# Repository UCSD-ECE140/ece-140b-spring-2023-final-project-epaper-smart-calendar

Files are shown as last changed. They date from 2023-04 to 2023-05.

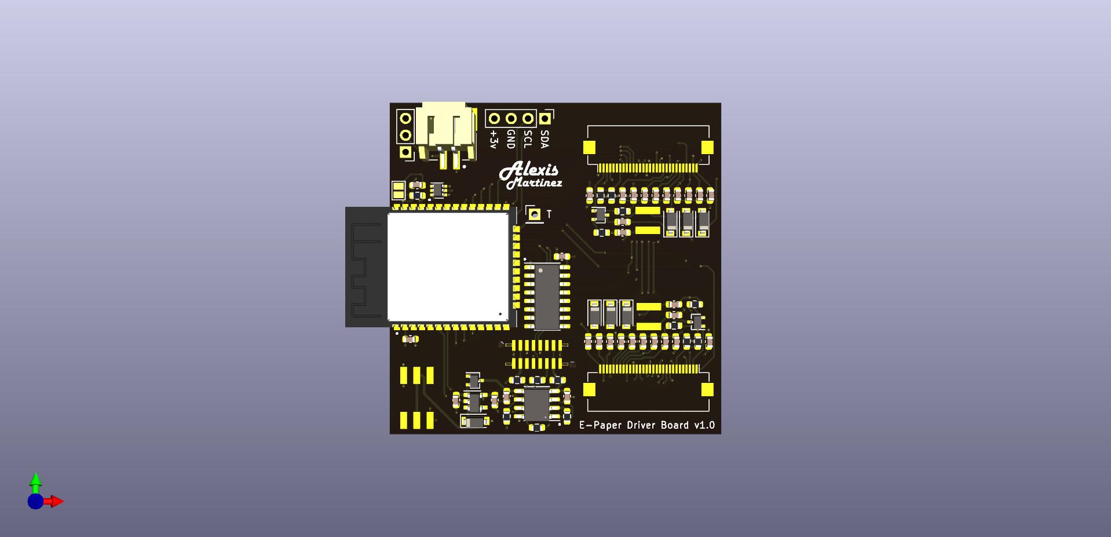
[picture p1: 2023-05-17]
PCB/Showcase Files/e_paper_display_driver_3d.jpg

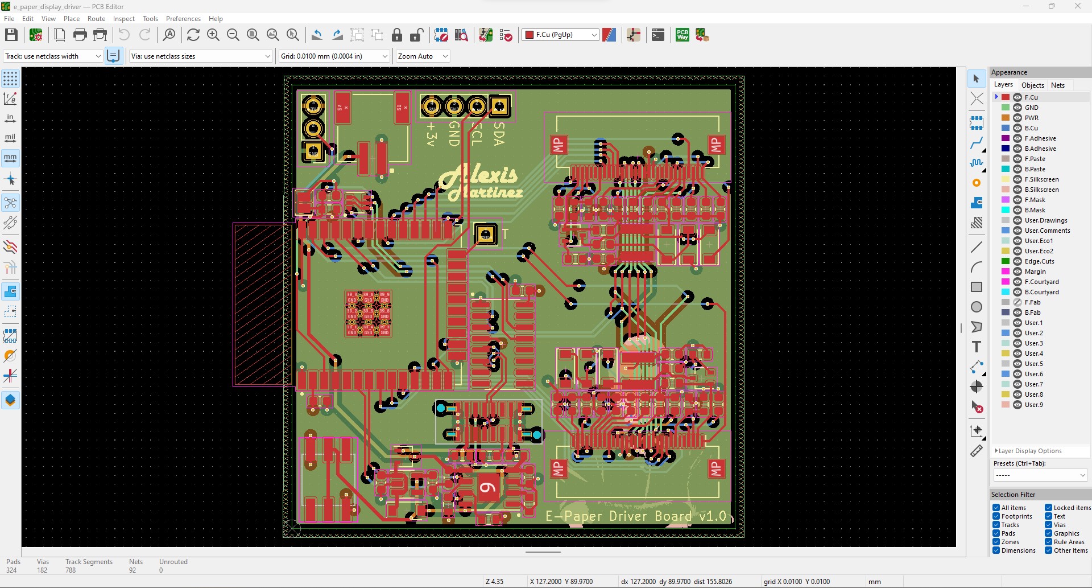
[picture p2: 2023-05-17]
PCB/Showcase Files/v1_screenshot_2d.jpg

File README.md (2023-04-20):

DEVELOPMENT SETUP:
Development is conducted using VS Code; the following extensions are required:
1. CPP Support (OPTIONAL: Syntax highlighting, misc. QoL CPP Extensions)
2. Arduino

Press control+shift+P and open the arduino library manager, then search for and install the following libraries:
1. WiFi
2. HTTPClient
3. ArduinoJson

TODO: ADD INSTRUCTIONS FOR BOARD UPLOAD

MISC. UNSORTED RESOURCES:
https://github.com/me-no-dev/arduino-esp32fs-plugin

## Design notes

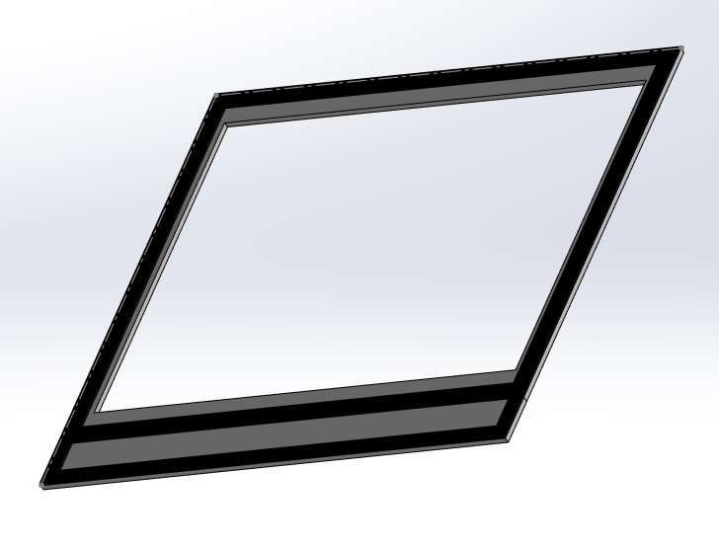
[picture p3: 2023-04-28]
E-Paper Calender CAD Files/Front Plate with Display Frame and Spacer.jpg

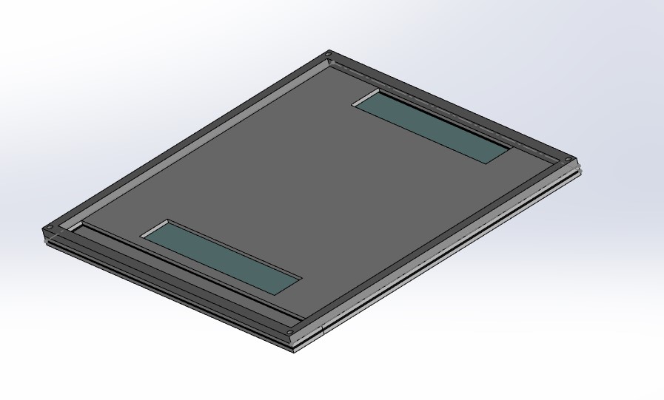
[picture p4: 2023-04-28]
E-Paper Calender CAD Files/Frame Attached to Backplate.jpg

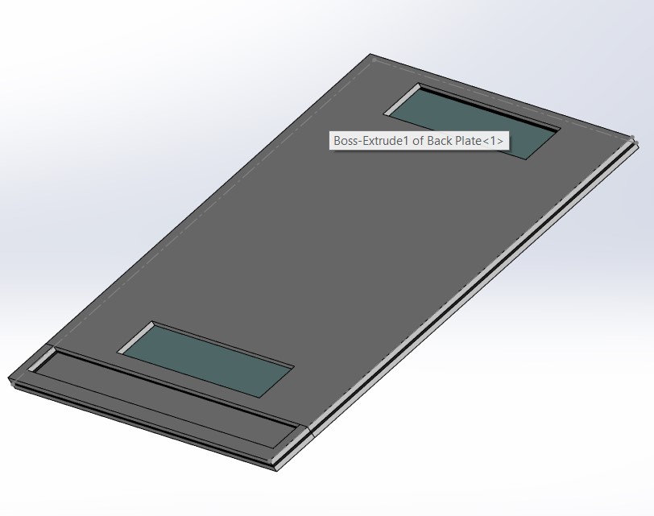
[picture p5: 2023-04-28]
E-Paper Calender CAD Files/Backplate Attached to Display Frame.jpg

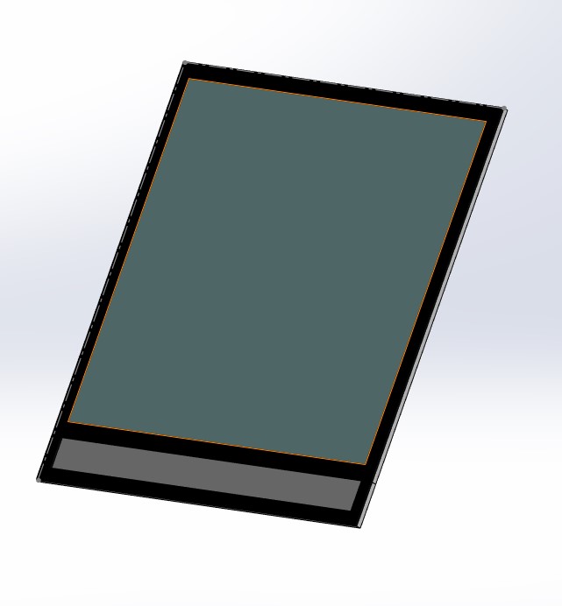
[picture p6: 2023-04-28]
E-Paper Calender CAD Files/Front Plate with Display Frame, Display, and Spacer.jpg

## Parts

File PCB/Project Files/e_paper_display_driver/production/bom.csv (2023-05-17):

Designator | Footprint | Quantity | Value | LCSC Part #
C1, C10, C11, C12, C14, C15, C16, C17, C18, C19, C2, C20, C21, C22, C23, C5, C6, C7, C8, C9 | 0603 | 20 | 1uF
C13, C3, C4 | 0603 | 3 | 100nF
C24, C25, C30, C31 | 0603 | 4 | 10uF
C26, C27, C28, C29 | 0603 | 4 | 4.7uF
D1 | D_SOD-123 | 1 | D_Shotkey
D2, D3, D4, D5, D6, D7 | D_SOD-123 | 6 | D
J1, J2 | Hirose_FH12-30S-0.5SH_1x30-1MP_P0.50mm_Horizontal | 2 | Conn_01x30
J3 | PinHeader_1x01_P2.54mm_Vertical | 1 | Conn_01x01
J4 | PinHeader_1x04_P2.54mm_Vertical | 1 | Conn_01x04
J5 | PinHeader_1x03_P2.54mm_Vertical | 1 | Conn_01x03
J6 | JST_S2B-PH-SM4-TB(LF)(SN) | 1 | S2B-PH-SM4
JP1 | SolderJumper-2_P1.3mm_Open_Pad1.0x1.5mm | 1 | SolderJumper_2_Open
L1, L2 | L_WPN4020H100MT | 2 | 10uH
Q1 | SOT-363_SC-70-6 | 1 | UMH3N
Q2, Q3 | SOT-323_SC-70 | 2 | Sil308EDL
Q4 | SOT-323_SC-70 | 1 | WST2005
R1, R10, R11, R15, R4, R5, R6, R8 | 0603 | 8 | 10k
R12, R13 | 0603 | 2 | 5.1k
R14 | 0603 | 1 | 1.2k
R2, R3 | 0603 | 2 | 3R
R7, R9 | 0603 | 2 | 1R
SW1 | TK-6580S-1 | 1 | SW_DPDT_x2
U1 | MODULE_ESP32-WROOM-32D | 1 | ESP32-WROOM-32D
U2 | SOIC-16_3.9x9.9mm_P1.27mm | 1 | CH340C
U3 | SOT-23-5 | 1 | ME6217C33M5G
U4 | HTSOP-8-1EP_3.9x4.9mm_P1.27mm_EP2.4x3.2mm | 1 | TP4056
USB1 | MC-110LS-L100 | 1 | USB_C_MC-110LS-L100

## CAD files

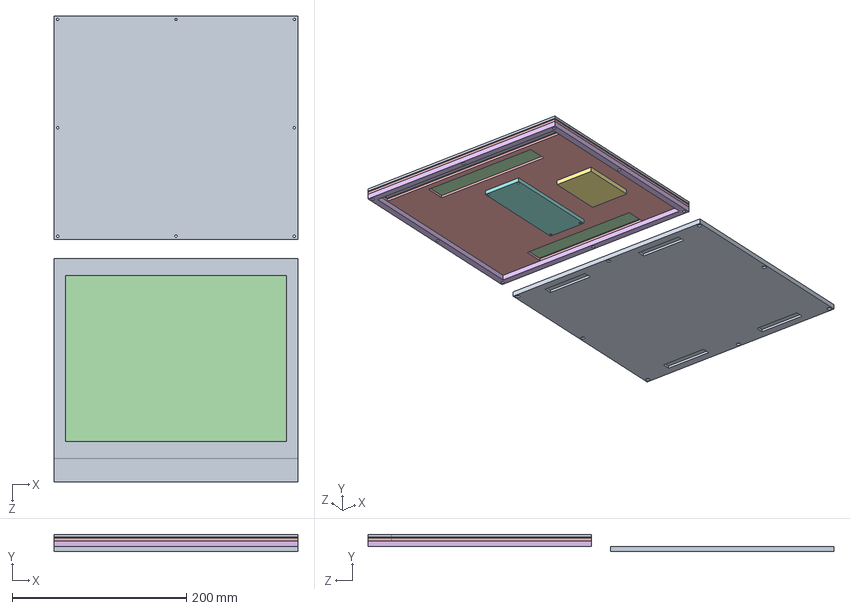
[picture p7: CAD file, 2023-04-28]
E-Paper Calender CAD Files/Assem1.SLDASM
280.0 x 19.6 x 535.4 mm
Front Plate
Display Frame Stand-In
Display Frame Spacer
Display Stand-in
Back Plate
Frame
Battery Stand-In
PCB Stand-in
Back Lid

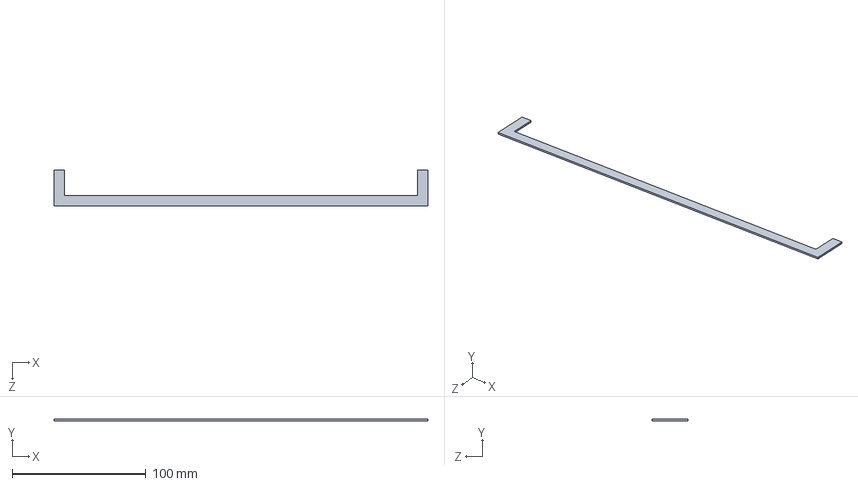
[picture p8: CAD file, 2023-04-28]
E-Paper Calender CAD Files/Display Frame Spacer.SLDPRT
280.0 x 1.25 x 27.0 mm

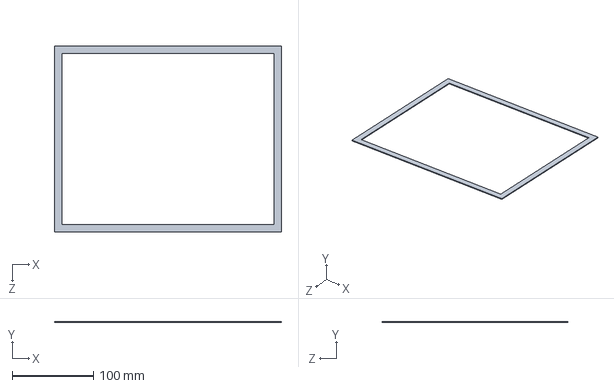
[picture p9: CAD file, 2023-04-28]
E-Paper Calender CAD Files/Display Frame Stand-In.SLDPRT
280.0 x 1.25 x 230.0 mm

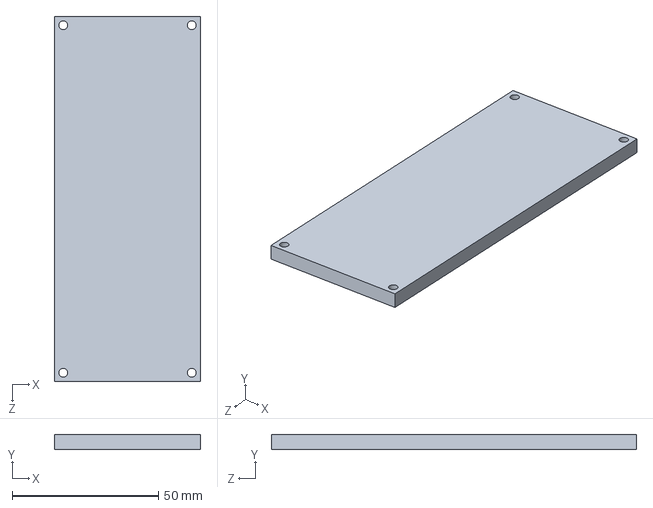
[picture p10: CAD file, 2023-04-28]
E-Paper Calender CAD Files/PCB Stand-in.SLDPRT
50.0 x 5.00 x 125.0 mm

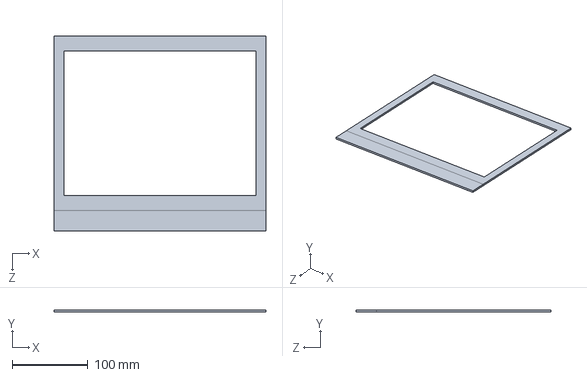
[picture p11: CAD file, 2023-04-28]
E-Paper Calender CAD Files/Front Plate.SLDPRT
280.0 x 3.00 x 257.0 mm

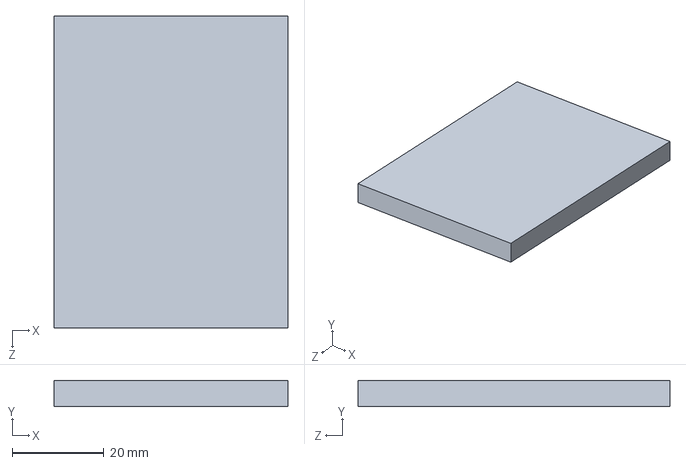
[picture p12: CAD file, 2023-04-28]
E-Paper Calender CAD Files/Battery Stand-In.SLDPRT
51.0 x 5.70 x 68.0 mm

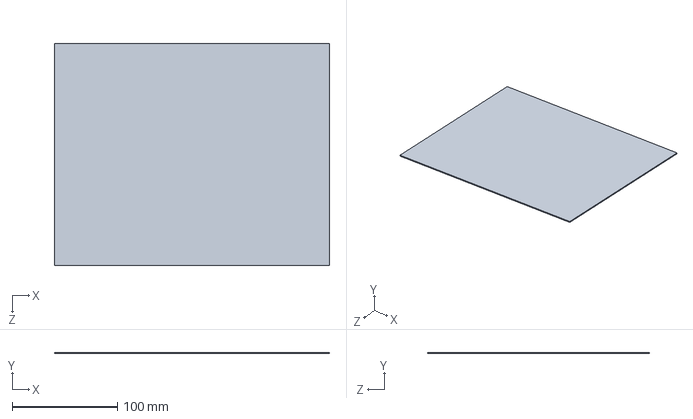
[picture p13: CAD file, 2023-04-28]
E-Paper Calender CAD Files/Display Stand-in.SLDPRT
261.0 x 1.25 x 211.0 mm

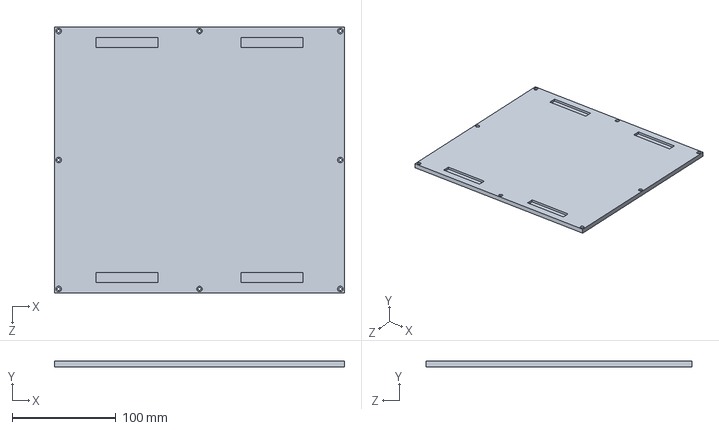
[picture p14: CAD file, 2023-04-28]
E-Paper Calender CAD Files/Back Lid.SLDPRT
280.0 x 6.00 x 257.0 mm

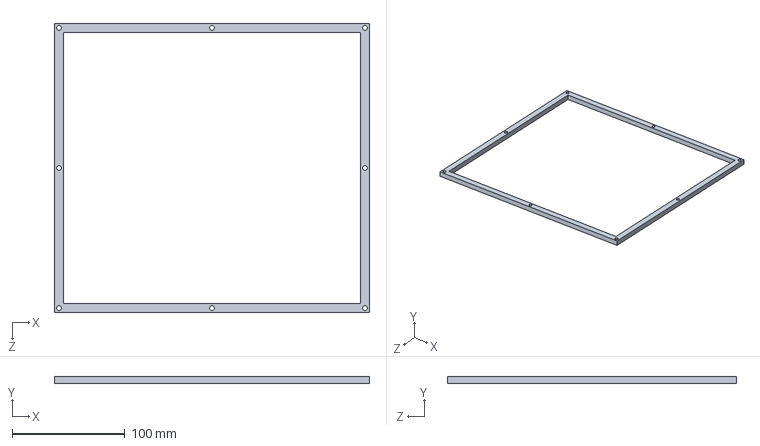
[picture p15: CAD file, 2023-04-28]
E-Paper Calender CAD Files/Frame.SLDPRT
280.0 x 6.35 x 257.0 mm

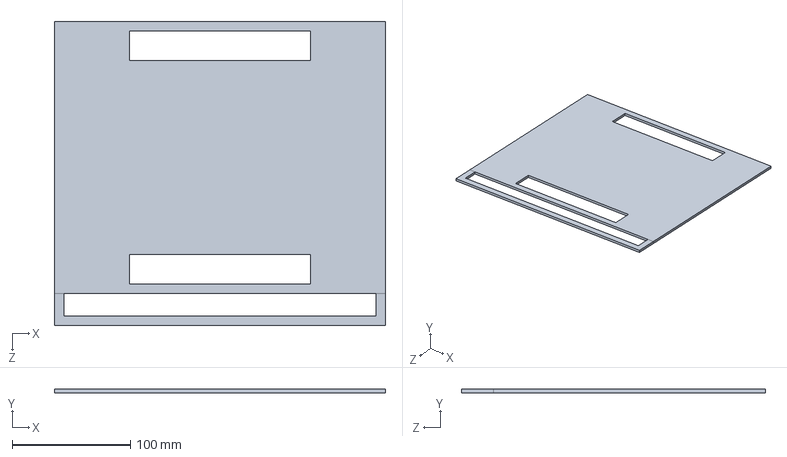
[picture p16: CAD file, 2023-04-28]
E-Paper Calender CAD Files/Back Plate.SLDPRT
280.0 x 3.00 x 257.0 mm

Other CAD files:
E-Paper Calender CAD Files/Back Plate.STL
E-Paper Calender CAD Files/Display Frame Stand-In.STL
E-Paper Calender CAD Files/Frame.STL
E-Paper Calender CAD Files/Front Plate.STL

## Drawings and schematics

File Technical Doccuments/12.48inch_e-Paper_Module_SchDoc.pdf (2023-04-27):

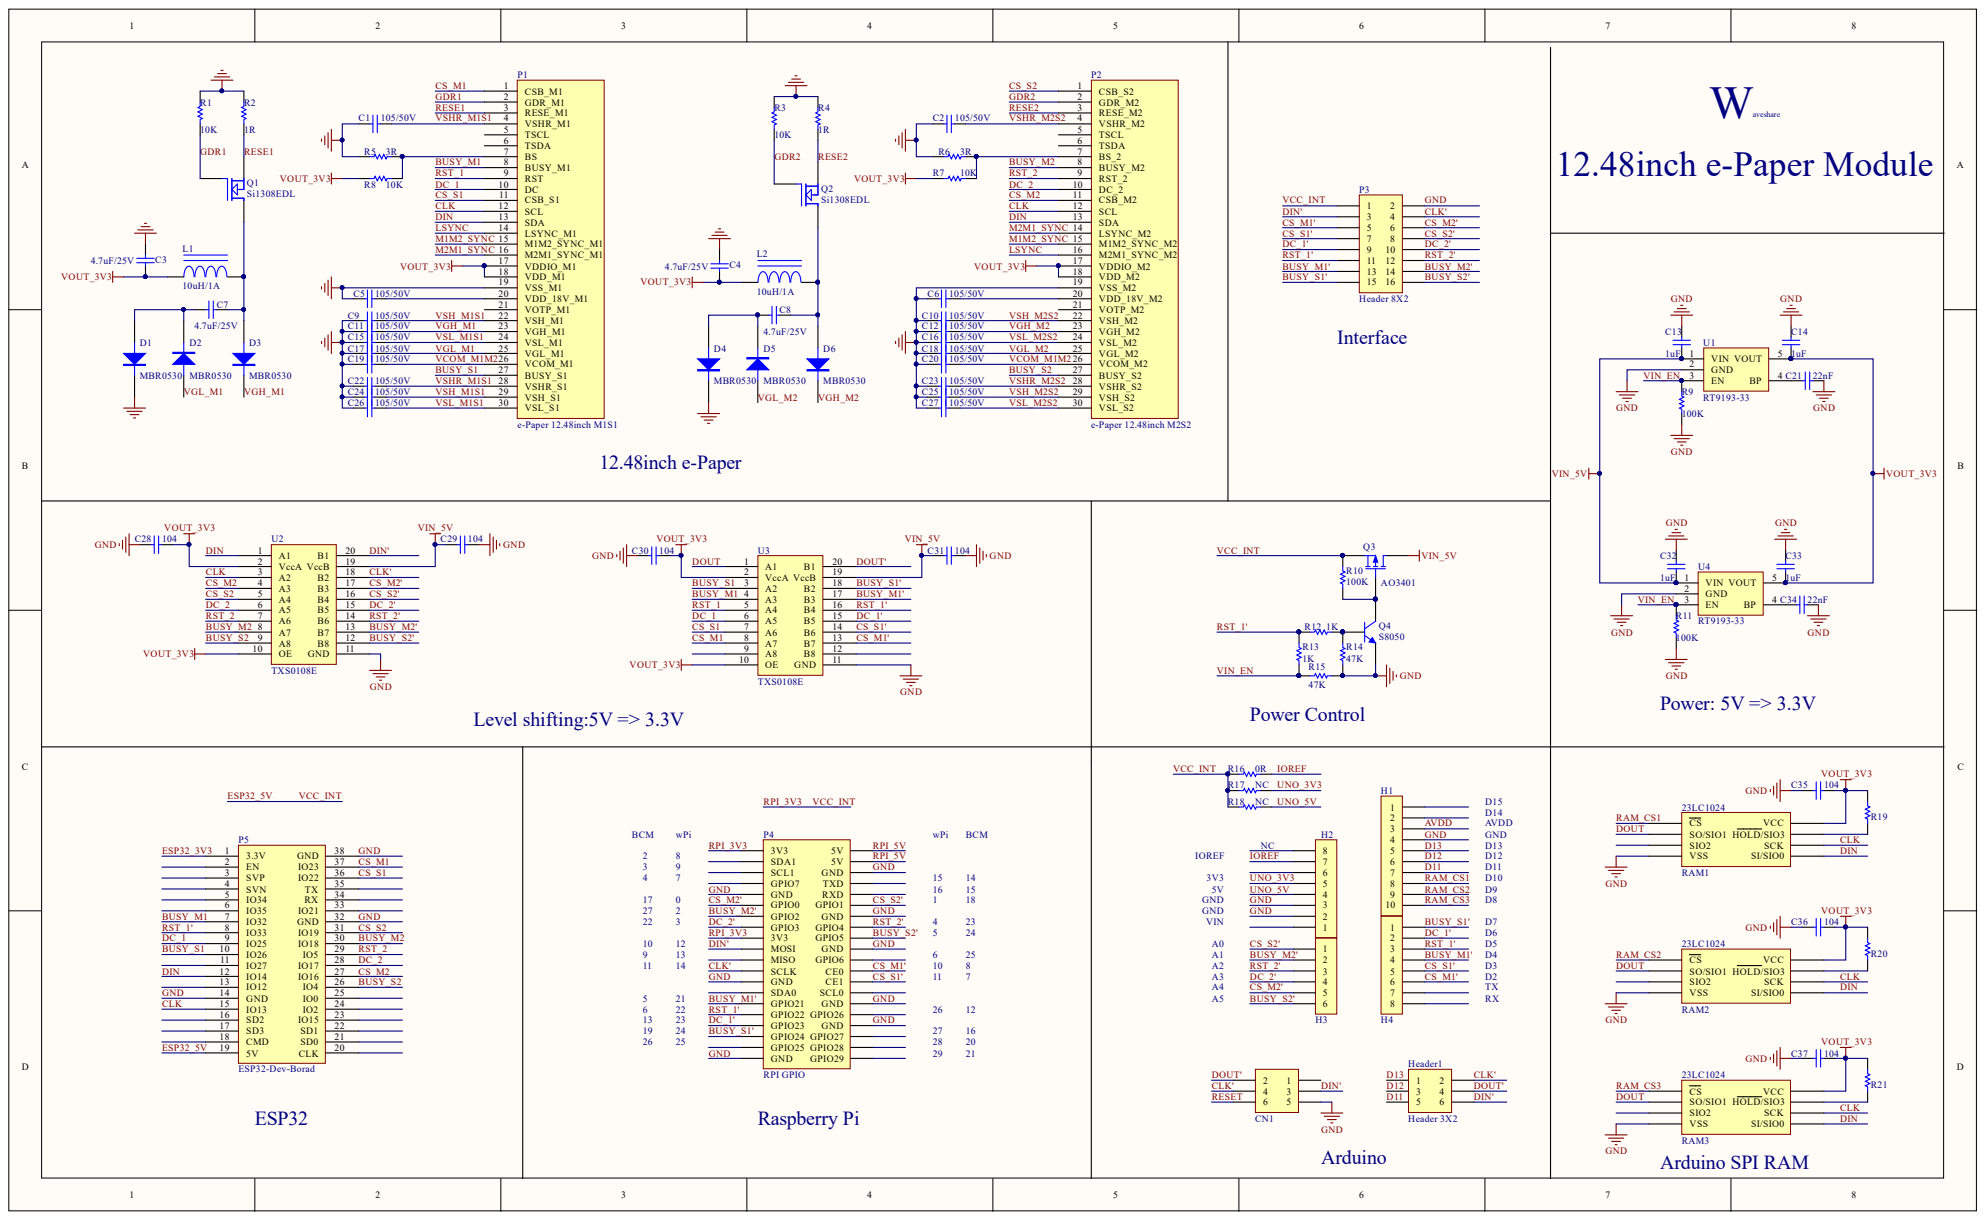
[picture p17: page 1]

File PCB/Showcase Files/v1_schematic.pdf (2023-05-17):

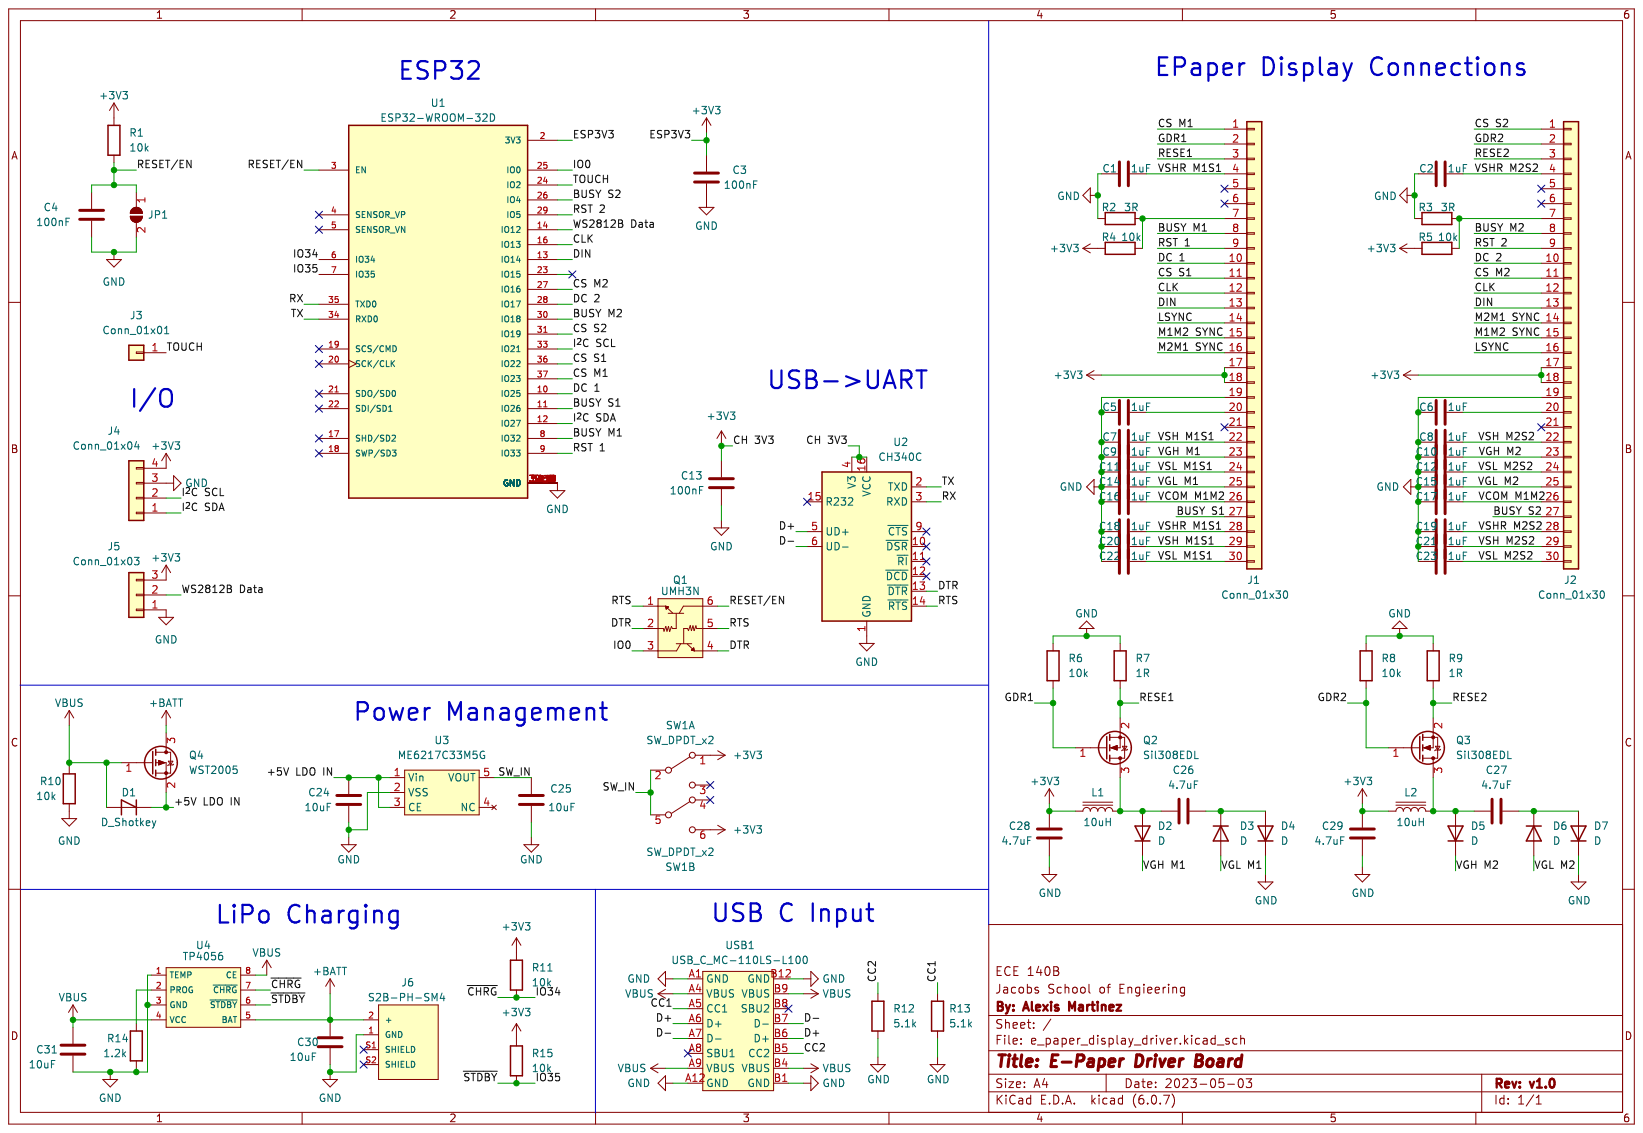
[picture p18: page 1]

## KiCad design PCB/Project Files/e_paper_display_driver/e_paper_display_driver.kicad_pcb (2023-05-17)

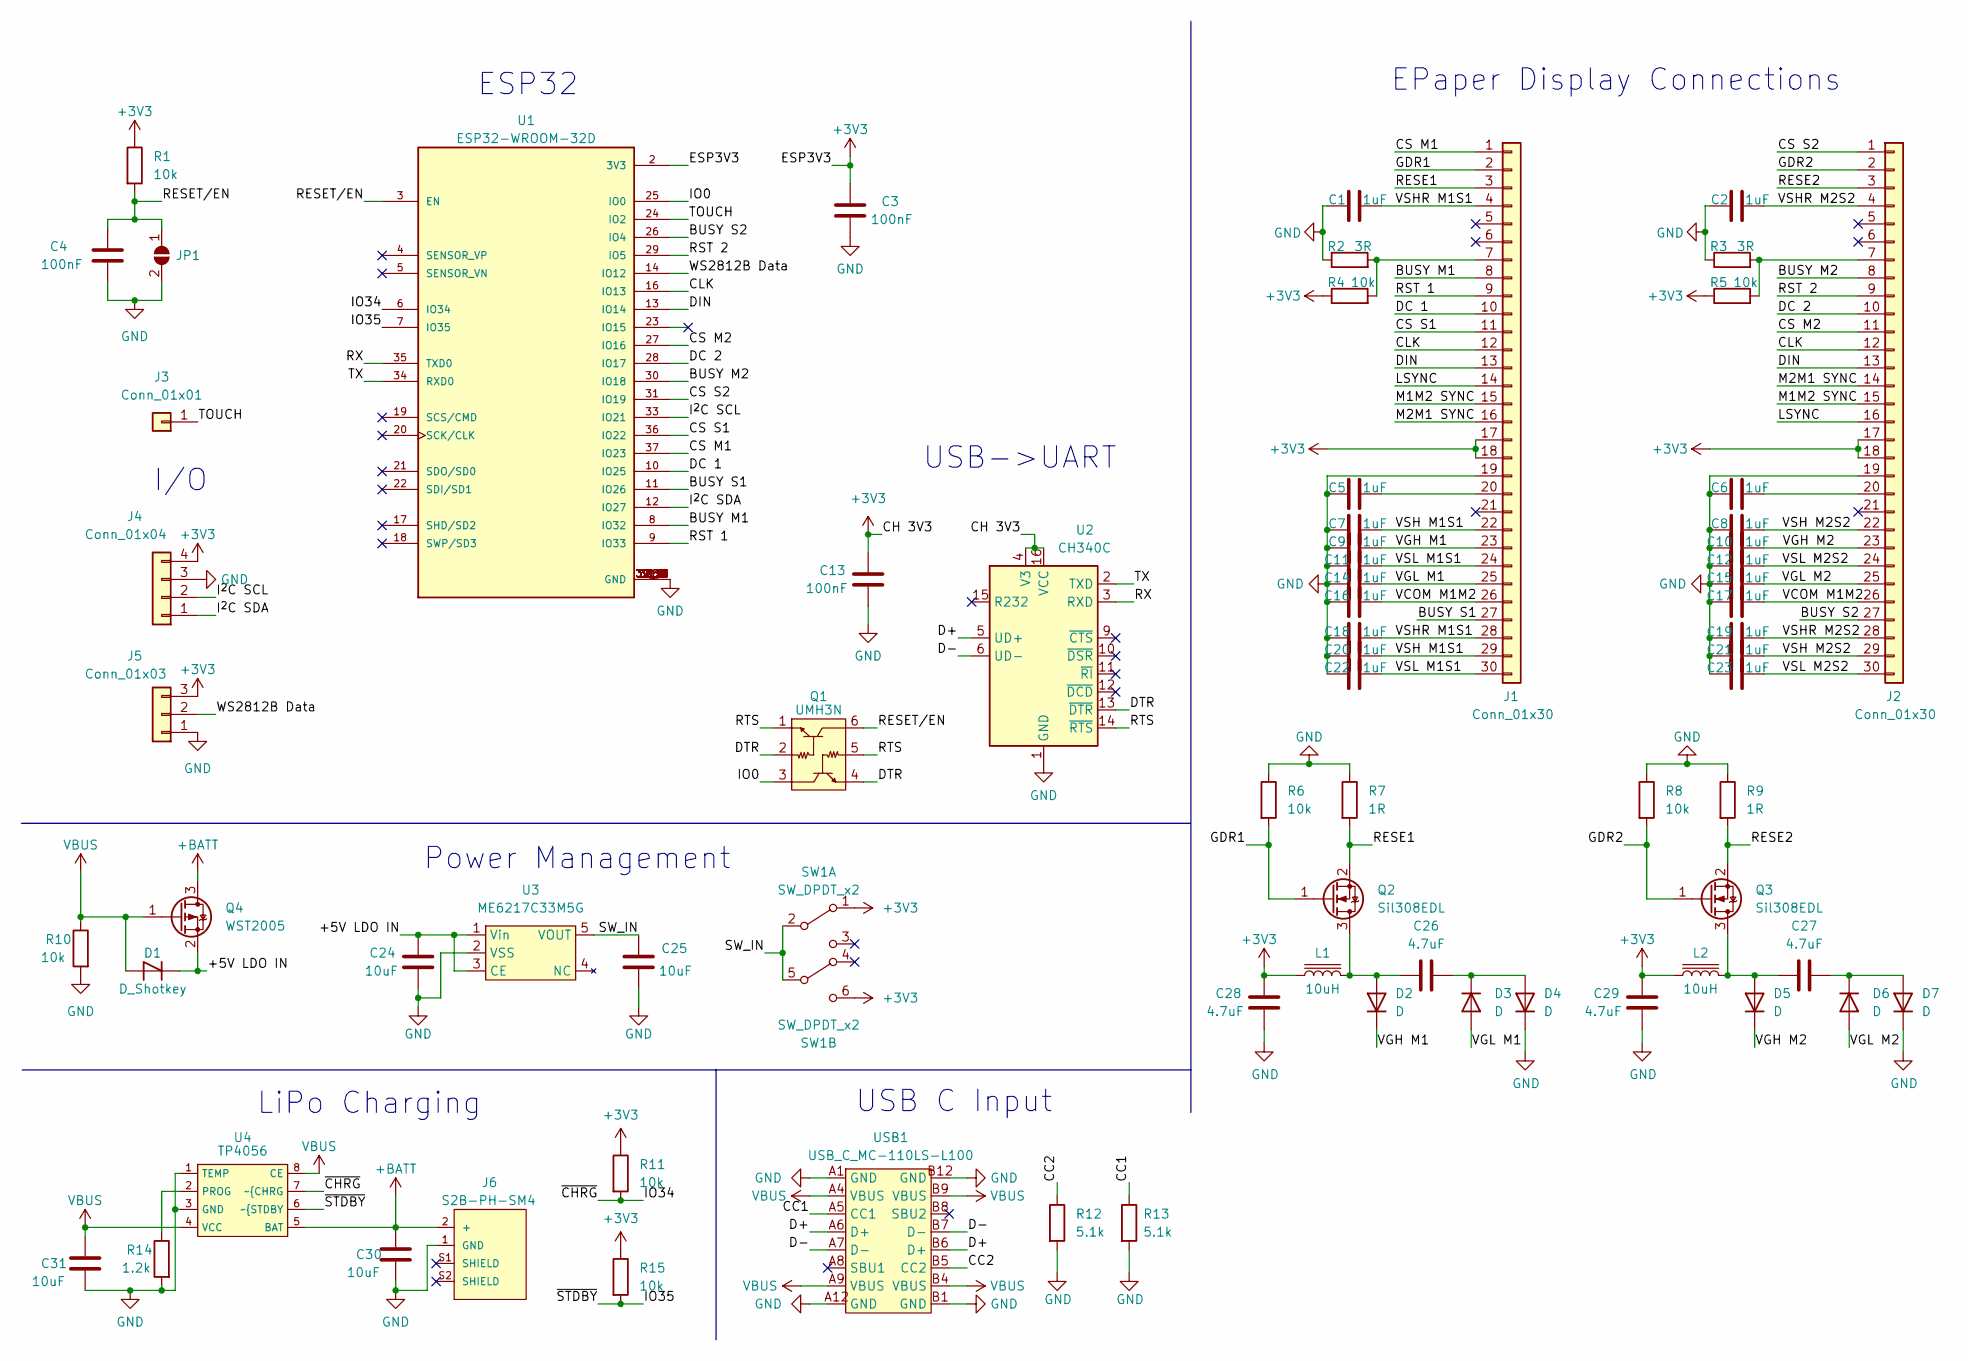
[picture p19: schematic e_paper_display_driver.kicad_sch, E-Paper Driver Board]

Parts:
C1, C2, C5, C6, C7, C8, C9, C10, C11, C12, C14, C15, C16, C17, C18, C19, C20, C21, C22, C23: 1uF; C_0603_1608Metric
C3, C4, C13: 100nF; C_0603_1608Metric
C24, C25, C30, C31: 10uF; C_0603_1608Metric
C26, C27, C28, C29: 4.7uF; C_0603_1608Metric
D1: D_Shotkey; D_SOD-123
D2, D3, D4, D5, D6, D7: D; D_SOD-123
J1, J2: Conn_01x30; Hirose_FH12-30S-0.5SH_1x30-1MP_P0.50mm_Horizontal
J3: Conn_01x01
J4: Conn_01x04; PinHeader_1x04_P2.54mm_Vertical
J5: Conn_01x03; PinHeader_1x03_P2.54mm_Vertical
J6: S2B-PH-SM4; JST_S2B-PH-SM4-TB(LF)(SN)
JP1: SolderJumper_2_Open; SolderJumper-2_P1.3mm_Open_Pad1.0x1.5mm
L1, L2: 10uH; L_WPN4020H100MT
Q1: UMH3N; SOT-363_SC-70-6
Q2, Q3: Sil308EDL; SOT-323_SC-70
Q4: WST2005; SOT-323_SC-70
R1, R4, R5, R6, R8, R10, R11, R15: 10k; R_0603_1608Metric
R2, R3: 3R; R_0603_1608Metric
R7, R9: 1R; R_0603_1608Metric
R12, R13: 5.1k; R_0603_1608Metric
R14: 1.2k; R_0603_1608Metric
SW1: SW_DPDT_x2; TK-6580S-1
U1: ESP32-WROOM-32D; MODULE_ESP32-WROOM-32D; PARTREV 1.9
U2: CH340C; SOIC-16_3.9x9.9mm_P1.27mm
U3: ME6217C33M5G; SOT-23-5
U4: TP4056; HTSOP-8-1EP_3.9x4.9mm_P1.27mm_EP2.4x3.2mm
USB1: USB_C_MC-110LS-L100; MC-110LS-L100

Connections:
+3V3: C3.1, C13.1, C28.1, C29.1, J1.17, J1.18, J2.17, J2.18, J4.4, J5.3, L1.1, L2.1, R1.1, R4.1, R5.1, R11.1, R15.1, SW1.1 (A), SW1.6 (C), U1.2 (3V3), U2.4 (V3), U2.16 (VCC)
+BATT: C30.1, J6.2 (+), Q4.3 (D), U4.5 (BAT)
/+5V LDO IN: C24.1, D1.1 (K), Q4.2 (S), U3.1 (Vin), U3.3 (CE)
/BUSY M1: J1.8, U1.8 (IO32)
/BUSY M2: J2.8, U1.30 (IO18)
/BUSY S1: J1.27, U1.11 (IO26)
/BUSY S2: J2.27, U1.26 (IO4)
/CC1: R13.1, USB1.A5 (CC1)
/CC2: R12.1, USB1.B5 (CC2)
/CLK: J1.12, J2.12, U1.16 (IO13)
/CS M1: J1.1, U1.37 (IO23)
/CS M2: J2.11, U1.27 (IO16)
/CS S1: J1.11, U1.36 (IO22)
/CS S2: J2.1, U1.31 (IO19)
/D+: U2.5 (UD+), USB1.A6 (D+), USB1.B6 (D+)
/D-: U2.6 (UD-), USB1.A7 (D-), USB1.B7 (D-)
/DC 1: J1.10, U1.10 (IO25)
/DC 2: J2.10, U1.28 (IO17)
/DIN: J1.13, J2.13, U1.13 (IO14)
/DTR: Q1.2, Q1.4, U2.13 (~DTR)
/GDR1: J1.2, Q2.1 (G), R6.2
/GDR2: J2.2, Q3.1 (G), R8.2
/IO0: Q1.3, U1.25 (IO0)
/IO34: R11.2, U1.6 (IO34), U4.7 (~{CHRG)
/IO35: R15.2, U1.7 (IO35), U4.6 (~{STDBY)
/I^{2}C SCL: J4.2, U1.33 (IO21)
/I^{2}C SDA: J4.1, U1.12 (IO27)
/LSYNC: J1.14, J2.16
/M1M2 SYNC: J1.15, J2.15
/M2M1 SYNC: J1.16, J2.14
/RESE1: J1.3, Q2.2 (S), R7.2
/RESE2: J2.3, Q3.2 (S), R9.2
/RESET/EN: C4.1, JP1.1 (A), Q1.6, R1.2, U1.3 (EN)
/RST 1: J1.9, U1.9 (IO33)
/RST 2: J2.9, U1.29 (IO5)
/RTS: Q1.1, Q1.5, U2.14 (~RTS)
/RX: U1.35 (TXD0), U2.3 (RXD)
/SW_IN: C25.1, SW1.2 (B), SW1.5 (B), U3.5 (VOUT)
/TOUCH: J3.1, U1.24 (IO2)
/TX: U1.34 (RXD0), U2.2 (TXD)
/VCOM M1M2: C16.2, C17.2, J1.26, J2.26
/VGH M1: C9.2, D2.1 (K), J1.23
/VGH M2: C10.2, D5.1 (K), J2.23
/VGL M1: C14.2, D3.2 (A), J1.25
/VGL M2: C15.2, D6.2 (A), J2.25
/VSH M1S1: C7.2, C20.2, J1.22, J1.29
/VSH M2S2: C8.2, C21.2, J2.22, J2.29
/VSHR M1S1: C1.2, C18.2, J1.4, J1.28
/VSHR M2S2: C2.2, C19.2, J2.4, J2.28
/VSL M1S1: C11.2, C22.2, J1.24, J1.30
/VSL M2S2: C12.2, C23.2, J2.24, J2.30
/WS2812B Data: J5.2, U1.14 (IO12)
GND: C1.1, C2.1, C3.2, C4.2, C5.1, C6.1, C7.1, C8.1, C9.1, C10.1, C11.1, C12.1, C13.2, C14.1, C15.1, C16.1, C17.1, C18.1, C19.1, C20.1, C21.1, C22.1, C23.1, C24.2, C25.2, C28.2, C29.2, C30.2, C31.2, D4.1 (K), D7.1 (K), J1.19, J2.19, J4.3, J5.1, J6.1 (GND), JP1.2 (B), R2.1, R3.1, R6.1, R7.1, R8.1, R9.1, R10.2, R12.2, R13.2, R14.2, U1.1 (GND), U1.15 (GND), U1.38 (GND), U1.39_1 (GND), U1.39_2 (GND), U1.39_3 (GND), U1.39_4 (GND), U1.39_5 (GND), U1.39_6 (GND), U1.39_7 (GND), U1.39_8 (GND), U1.39_9 (GND), U1.39_10 (GND), U1.39_11 (GND), U1.39_12 (GND), U1.39_13 (GND), U1.39_14 (GND), U1.39_15 (GND), U1.39_16 (GND), U1.39_17 (GND), U1.39_18 (GND), U1.39_19 (GND), U1.39_20 (GND), U1.39_21 (GND), U2.1 (GND), U3.2 (VSS), U4.1 (TEMP), U4.3 (GND), USB1.A1 (GND), USB1.A12 (GND), USB1.B1 (GND), USB1.B12 (GND)
unnamed: C5.2, J1.20
unnamed: C6.2, J2.20
unnamed: C26.1, D2.2 (A), L1.2, Q2.3 (D)
unnamed: C26.2, D3.1 (K), D4.2 (A)
unnamed: C27.1, D5.2 (A), L2.2, Q3.3 (D)
unnamed: C27.2, D6.1 (K), D7.2 (A)
unnamed: J1.7, R2.2, R4.2
unnamed: J2.7, R3.2, R5.2
unnamed: R14.1, U4.2 (PROG)
VBUS: C31.1, D1.2 (A), Q4.1 (G), R10.1, U4.4 (VCC), U4.8 (CE), USB1.A4 (VBUS), USB1.A9 (VBUS), USB1.B4 (VBUS), USB1.B9 (VBUS)

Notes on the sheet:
I/O
EPaper Display Connections
USB->UART
USB C Input
LiPo Charging
Power Management
ESP32

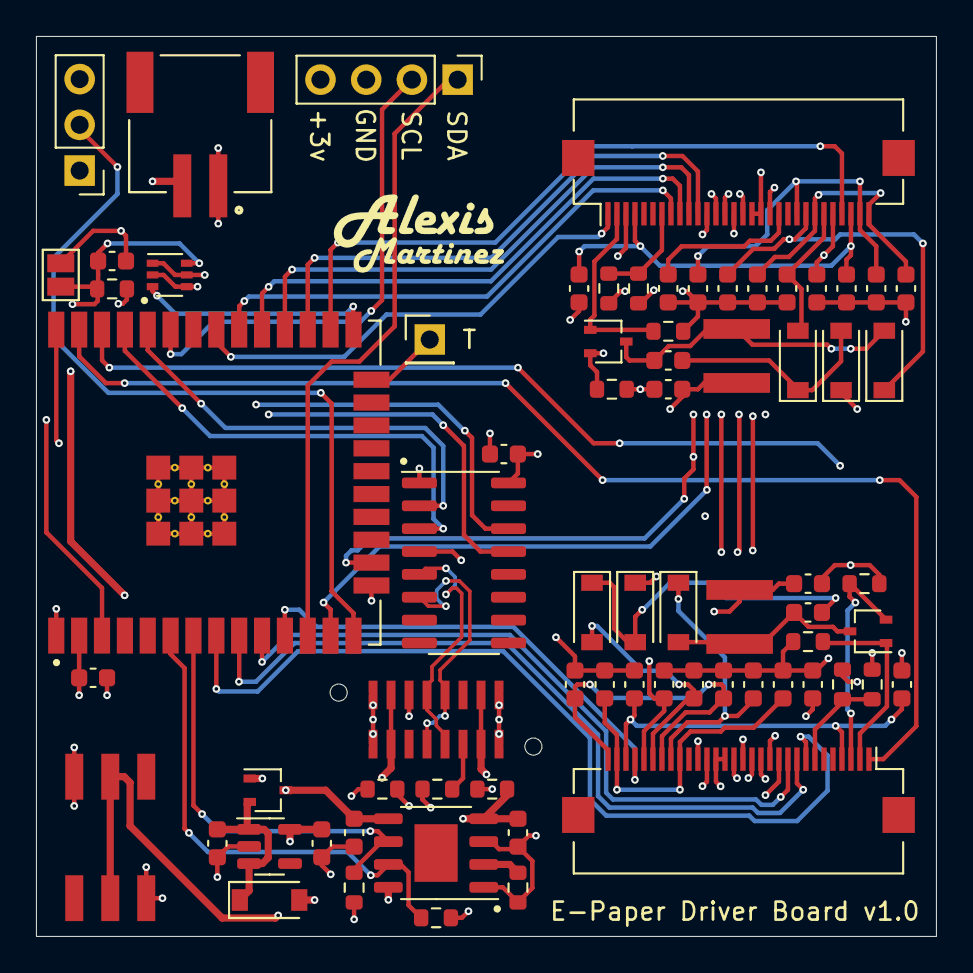
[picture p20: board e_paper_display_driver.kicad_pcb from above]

Board: 4 copper layers, 50.0 x 50.0 mm, 72 parts (0 on the bottom side), 63 nets.

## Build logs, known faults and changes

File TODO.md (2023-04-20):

DANNY:
Test existing code with esp32 board and figure out whether it needs to be changed to make it work.

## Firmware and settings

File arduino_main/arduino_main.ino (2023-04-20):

//INITIAL SPAGHETTI CODE, REMEMBER TO DESPAGHETTIFY BEFORE FURTHER DEVELOPMENT

#include <WiFi.h>
#include <HTTPClient.h>
#include <ArduinoJson.h>
#include <SPIFFS.h>

String ssid;
String password;
String apiKey;
String calendarId;

void loadSettingsFromJson()
{
    if (!SPIFFS.begin(true))
    {
        Serial.println("Failed to mount SPIFFS");
        return;
    }

    File file = SPIFFS.open("/settings.json");
    if (!file)
    {
        Serial.println("Failed to open settings.json");
        return;
    }

    size_t size = file.size();
    std::unique_ptr<char[]> buf(new char[size]);
    file.readBytes(buf.get(), size);
    file.close();

    DynamicJsonDocument doc(1024);
    DeserializationError error = deserializeJson(doc, buf.get());

    if (error)
    {
        Serial.println("Failed to parse settings.json");
        return;
    }

    ssid = doc["ssid"].as<String>();
    password = doc["password"].as<String>();
    apiKey = doc["apiKey"].as<String>();
    calendarId = doc["calendarId"].as<String>();
}

void setup()
{
    Serial.begin(115200);
    loadSettingsFromJson();

    WiFi.begin(ssid.c_str(), password.c_str());
    while (WiFi.status() != WL_CONNECTED)
    {
        delay(1000);
        Serial.println("Connecting to Wi-Fi...");
        //TODO: maybe after like 5 successive failures, prompt user to reenter password or try different network?
        
    }
    Serial.println("Connected to Wi-Fi");
}

void loop()
{
    if (WiFi.status() == WL_CONNECTED)
    {
        HTTPClient http;
        String url = "https://www.googleapis.com/calendar/v3/calendars/" + String(calendarId) + "/events?key=" + String(apiKey);
        http.begin(url);
        int httpResponseCode = http.GET();

        if (httpResponseCode > 0)
        {
            String payload = http.getString();
            DynamicJsonDocument doc(4096);
            deserializeJson(doc, payload);

            JsonArray items = doc["items"];

            for (JsonObject item : items)
            {
                String summary = item["summary"].as<String>();
                String location = item["location"].as<String>();
                String startTime = item["start"]["dateTime"].as<String>();
                String endTime = item["end"]["dateTime"].as<String>();

                Serial.println("Summary: " + summary);
                Serial.println("Location: " + location);
                Serial.println("Start Time: " + startTime);
                Serial.println("End Time: " + endTime);
                Serial.println("---------------------------");
            }
        }
        else
        {
            Serial.printf("Error: %d", httpResponseCode);
        }
        http.end();
    }

    //TODO: CURRENTLY FETCHES AND REFRESHES EVERY FIVE MINUTES, CHANGE AS NEEDED

    delay(300000);
}

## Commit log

2023-04-27 Added PCB Stuff
    [e_paper_display_driver.kicad_pcb, e_paper_display_driver.kicad_sch]
2023-04-27 Added Initial CAD Files and Display Measurements
    [Back Plate.SLDPRT, Back Plate.STL, Display Frame Stand-In.SLDPRT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]
2023-04-28 Deleted Old CAD Files
    [Back Plate.SLDPRT, Back Plate.STL, Display Frame Stand-In.SLDPRT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]
2023-04-28 Updated CAD Files
    [Assem1.SLDASM, Back Lid.SLDPRT, Back Plate.SLDPRT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]
2023-05-02 PDF Schematic
2023-05-17 PCB Updates
    [bom.csv, designators.csv, e_paper_display_driver.kicad_pcb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]
